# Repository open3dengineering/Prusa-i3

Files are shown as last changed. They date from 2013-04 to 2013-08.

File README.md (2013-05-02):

O3DE-Prusa I3
=============

This is a improved version of the Prusa i3 3D Printer. 

*see [http://reprap.org/wiki/Prusa_i3](http://reprap.org/wiki/Prusa_i3).*

Improvements:
-------------
* Aluminium Frame has now a Y-Plate with 3 points to attach the Heatbed ( compatible with MK2a + MK2b  Heatbed )
* Aluminium Frame had some little bugs + the milling time has decreased to 50%. 
* x-motor-end has been moved 5mm outwards to don't bump into the RAMPS electronics board.
* teeth profile on the x-carriage has been seperated to print better ( teeth part is printed with a 0.3mm nozzle layer height 0.2mm )
* y-beltholder has been improved to print faster
* addons for now a clamp-on spoolholder 
* extruder is addapted from EiNSTeiN variant, with some improvements for printing and usage, added fanholder ( there is still some work to do )

Design tools:
-------------

The Extruder is still in openscad design , the rest ( exept the Aluminium Frame ) was imported into Blender.
The Aluminium Frame has been redesigned in QCAD..

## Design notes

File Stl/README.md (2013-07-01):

O3DE-Prusa I3 stl files
=============

This are all the printed parts, exept the extruder that resigns in ../Extruder/stl.
There are some minor tweaks, please refere to the manual for assembly instructions.

plate-1-04mm.stl 
	* print with 0.4mm layer height 

plate-2-02mm.stl
	* print with 0.2mm layer height

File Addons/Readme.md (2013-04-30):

Addons for the Prus i3 
======================

Spool Holder
------------

The spool holder is clamped ontop into the Aluminium Frame facing to the backside. 
We left enough place so all 1KG spools will fit.

Files:

* i3_spool_holder.stl
* ../Blender/i3_spool_holder.blend

Power Supply Cover
------------------

*Have a look at [http://www.thingiverse.com/thing:40377](http://www.thingiverse.com/thing:40377).*

There are two files 

* Vision_12_Volt_Power_Supply_Cover_-_Final_-_No_Switch_Hole.stl ( without on/off switch)
* Vision_12_Volt_Power_Supply_Cover_-_Final.stl ( with on/off switch)

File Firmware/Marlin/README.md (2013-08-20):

Marlin Firmware for the O3DE-Prusa I3
=============

This is a preconfigured Marlin Firmware for the O3DE-Prusa I3. 

*original [https://github.com/ErikZalm/Marlin/](https://github.com/ErikZalm/Marlin/).*

Installation Instructions:
-------------
* Download Arduino 1.0.5 from *[http://arduino.cc/en/Main/Software](http://arduino.cc/en/Main/Software).*
* Install /ArduinoAddons/Arduino_1.x.x/u8glib_arduino_v1.12.zip into your Arduino library directory *see [http://arduino.cc/en/Guide/Libraries](http://arduino.cc/en/Guide/Libraries)*
* on Windows install arduino Drivers located in the arduino drivers directory ( right click arduino.inf and select install )
* To use the Taurino Classic and Taurino Power ( both Arduino Mega clones ) on Windows 8/7/Vista/XP 32 and 64 bit install the USB driver from [ftp://ftp.open3dengineering.org/pub/Taurino_USB_Driver_Windows/RRD_RUMBA_TAURINO_DriverSetup.exe](ftp://ftp.open3dengineering.org/pub/Taurino_USB_Driver_Windows/RRD_RUMBA_TAURINO_DriverSetup.exe)
* Open /Marlin/Marlin.ino with the Arduino IDE 
* set your Boardtype to "Arduino Mega 2560" and select the coresponding serial interface
* upload the Firmware ( File->Upload )

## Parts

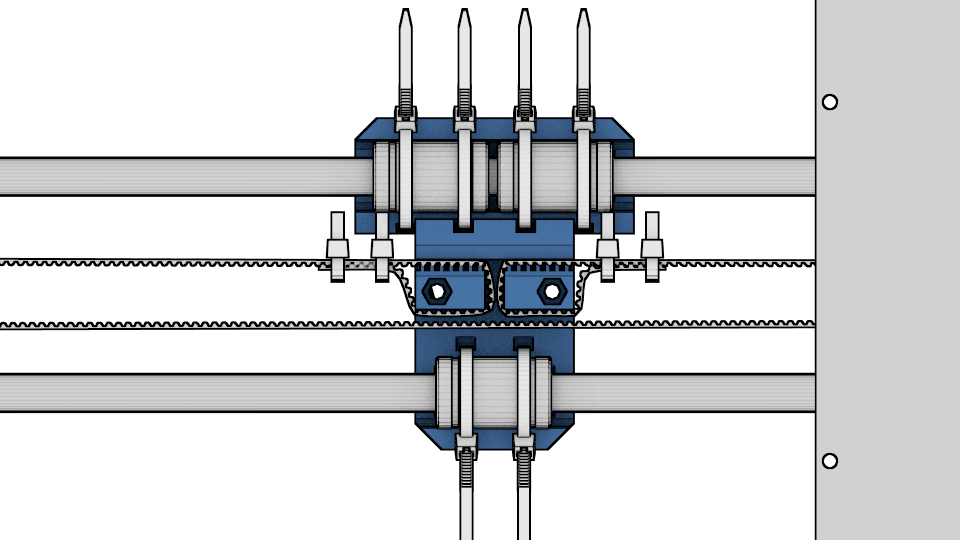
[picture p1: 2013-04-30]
Manual/media/assembed_parts/x8.png

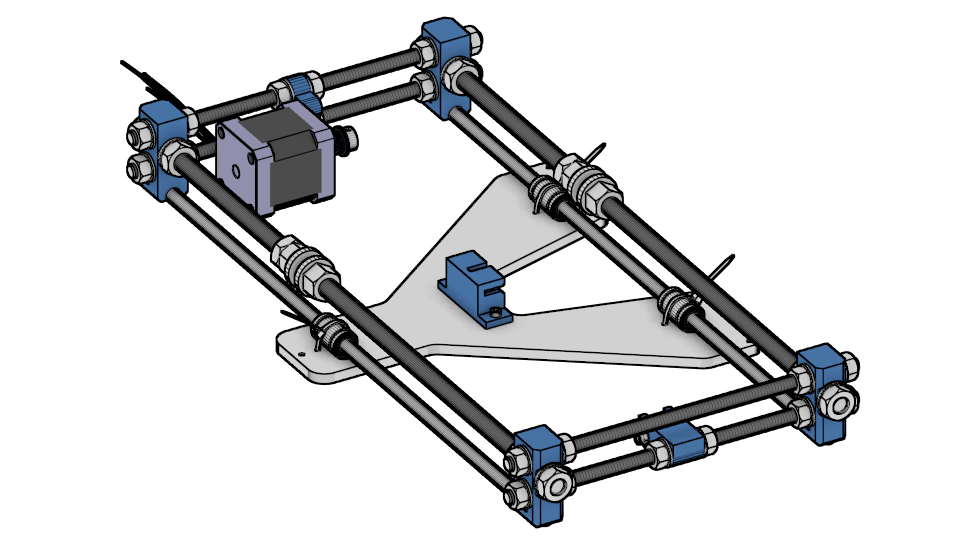
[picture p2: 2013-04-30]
Manual/media/assembed_parts/Y12.png

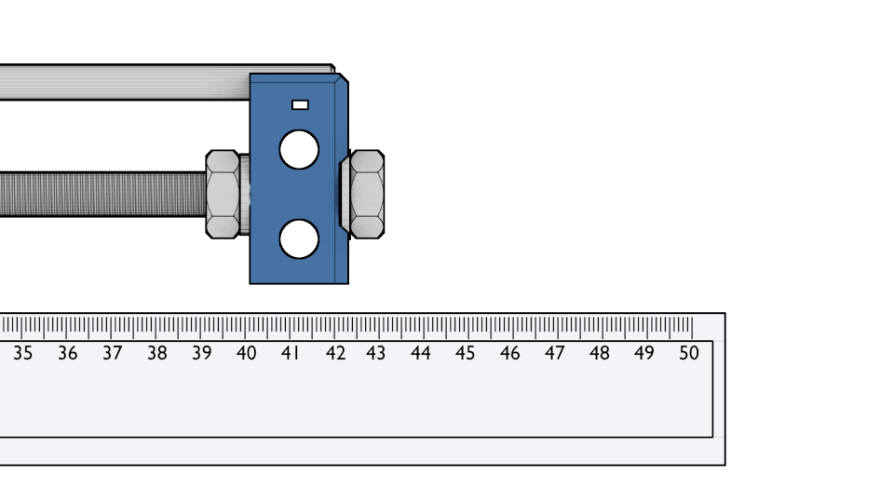
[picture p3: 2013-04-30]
Manual/media/assembed_parts/YA3.png

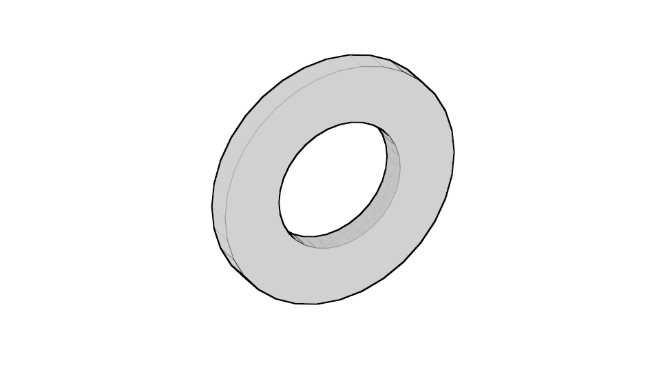
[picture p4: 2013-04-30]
Manual/media/single_parts/DIN 125 M10.png

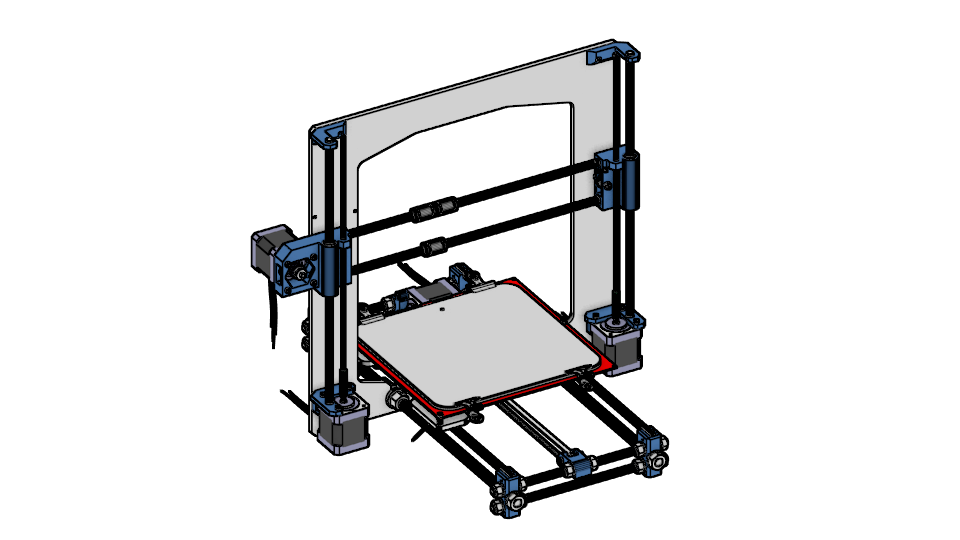
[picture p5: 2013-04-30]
Manual/media/assembed_parts/x5.png

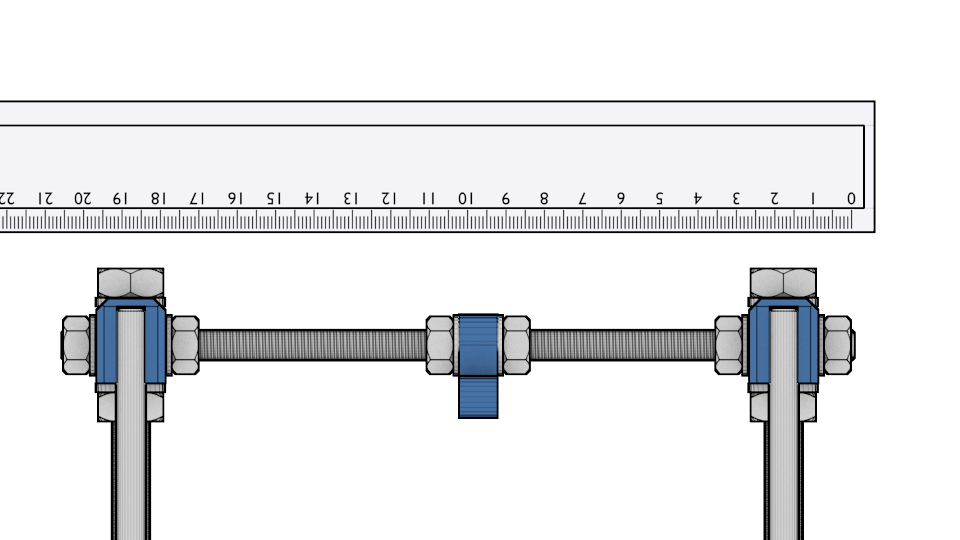
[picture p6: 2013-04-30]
Manual/media/assembed_parts/YA6.png

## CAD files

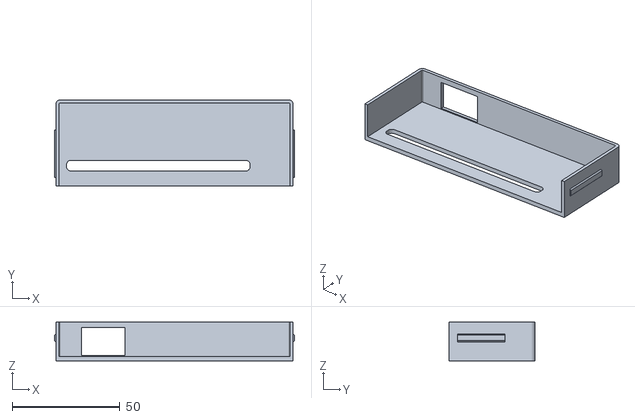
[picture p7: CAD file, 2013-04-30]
Addons/Vision_12_Volt_Power_Supply_Cover_-_Final.stl
111.2 x 40.0 x 18.0

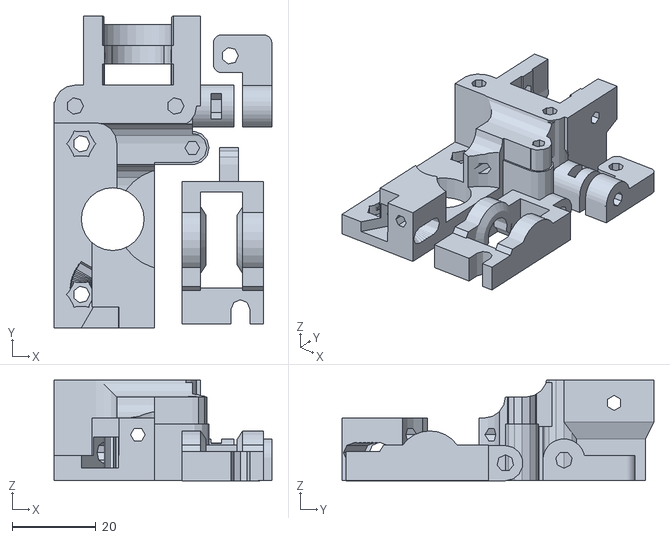
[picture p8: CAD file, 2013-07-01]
Extruder/stl/compact-extruder_o3d_ceramic (repaired).stl
52.0 x 74.5 x 24.0

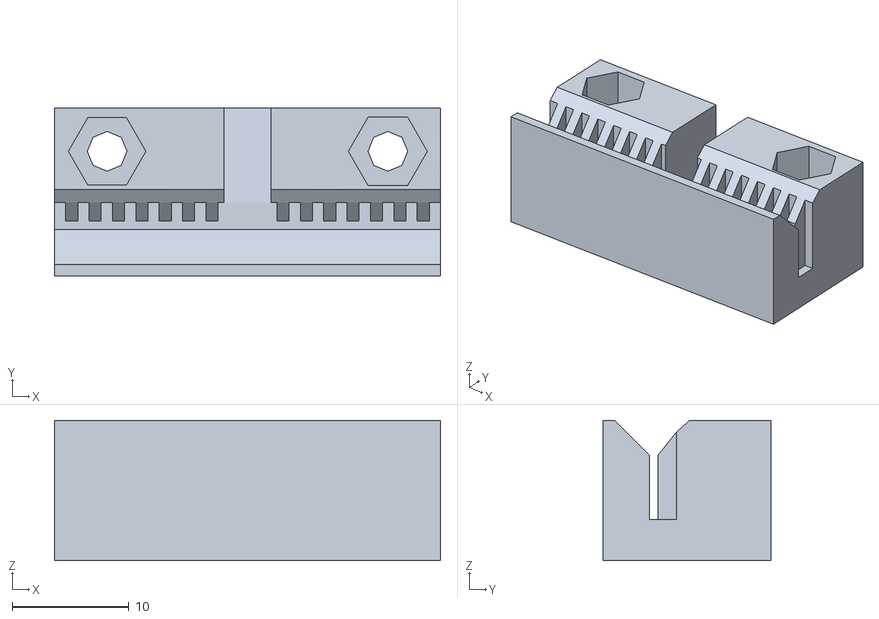
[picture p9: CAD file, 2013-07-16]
Stl/x-carriage-teeth-gt2.stl
33.0 x 14.4 x 12.0

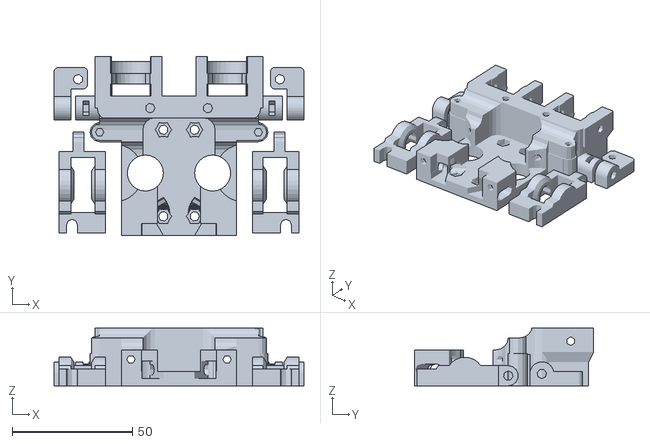
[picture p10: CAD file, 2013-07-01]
Extruder/stl/compact-dual-extruder_o3d_ceramic (repaired).stl
104.0 x 74.5 x 24.0

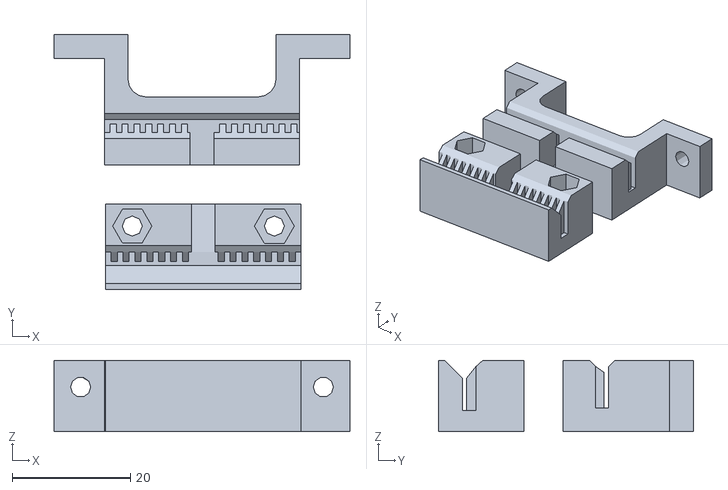
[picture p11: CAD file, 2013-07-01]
Stl/plate-2-02mm.stl
50.0 x 43.0 x 12.0

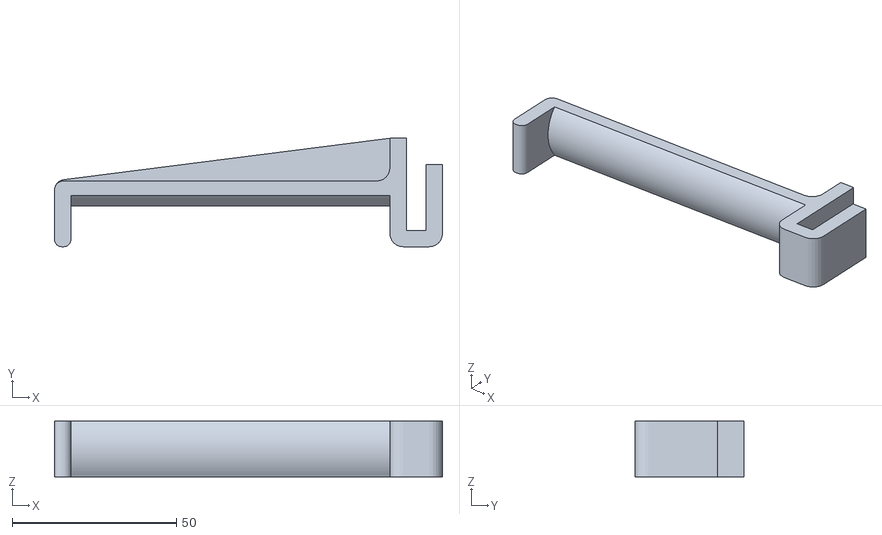
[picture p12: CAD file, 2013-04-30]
Addons/i3_spool_holder.stl
118.0 x 33.0 x 17.0

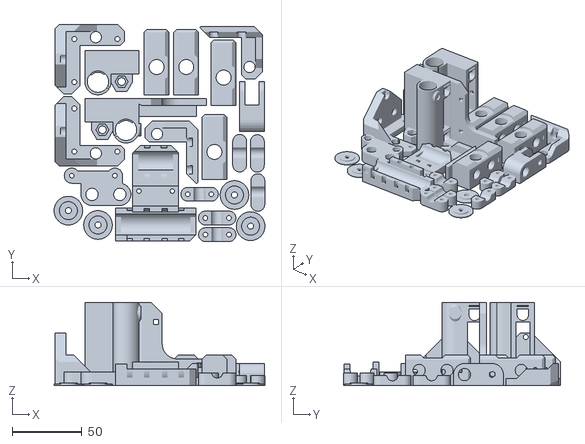
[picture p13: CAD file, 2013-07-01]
Stl/plate-1-04mm.stl
151.8 x 156.2 x 60.0

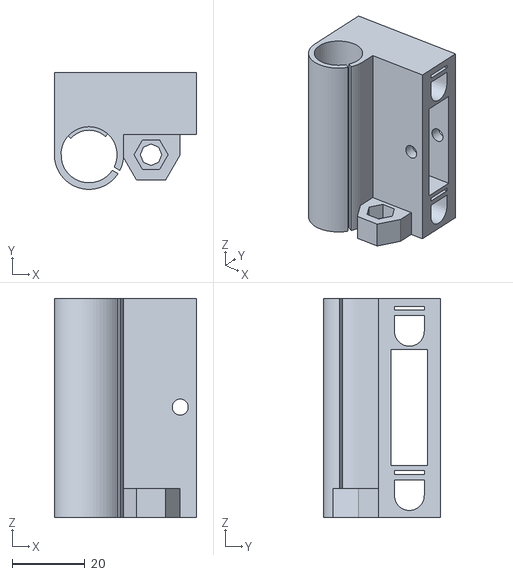
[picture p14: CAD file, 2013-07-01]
Stl/x-idler.stl
39.0 x 32.0 x 60.0

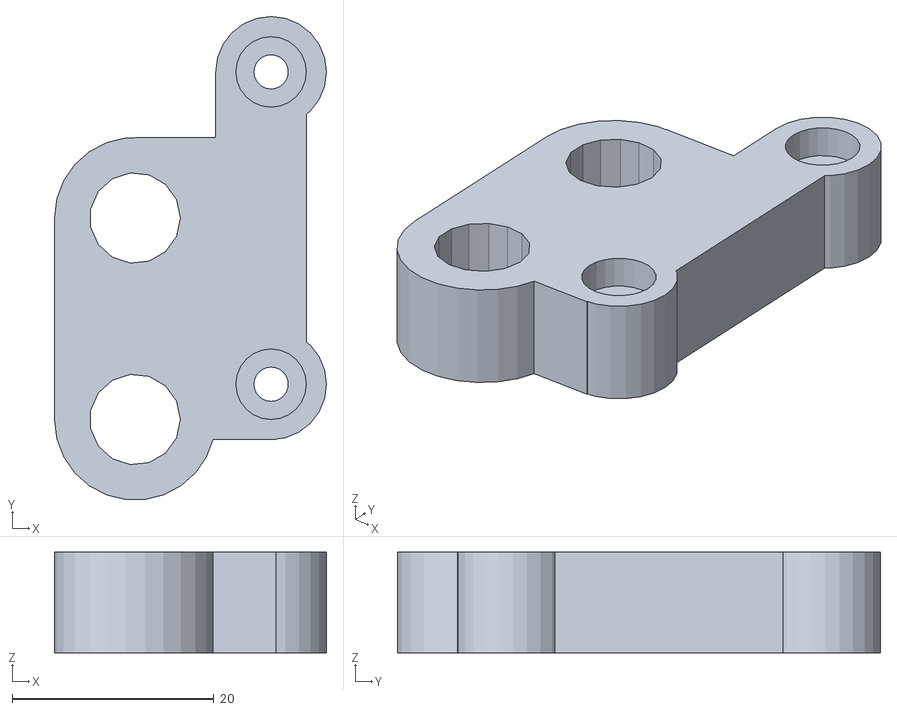
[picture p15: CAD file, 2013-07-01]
Stl/y-motor.stl
27.0 x 47.9 x 10.0

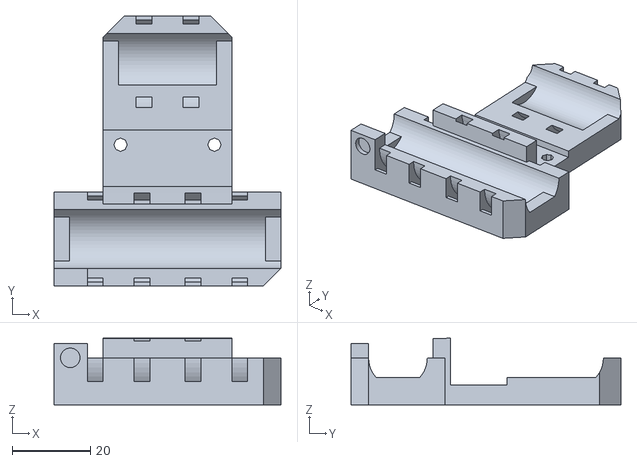
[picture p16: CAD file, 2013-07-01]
Stl/x-carriage-holder.stl
58.0 x 69.0 x 17.0

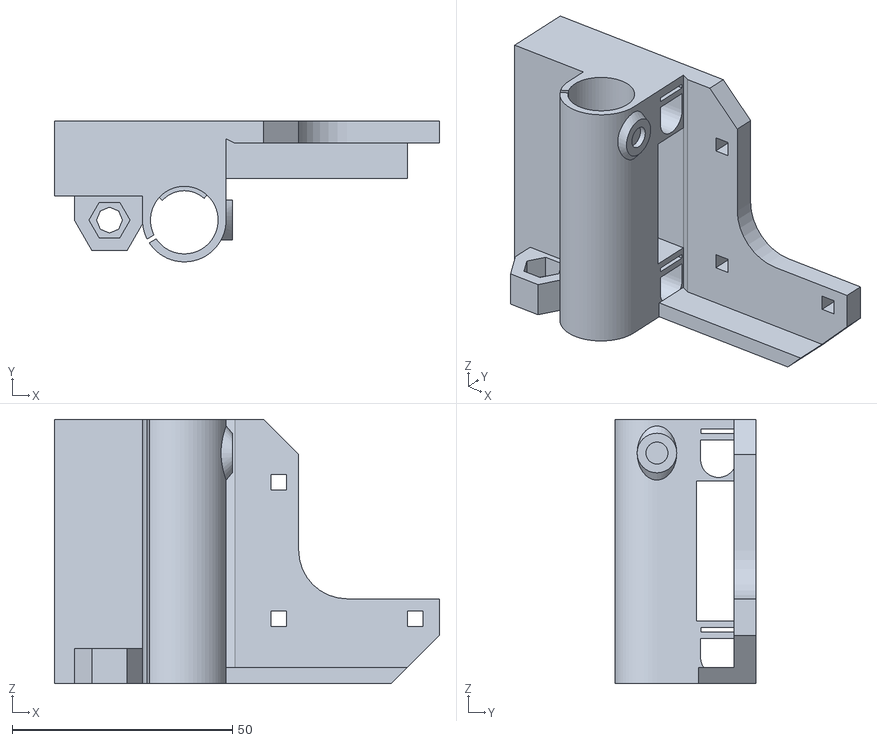
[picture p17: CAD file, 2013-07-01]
Stl/x-motor-end.stl
87.5 x 32.0 x 60.0

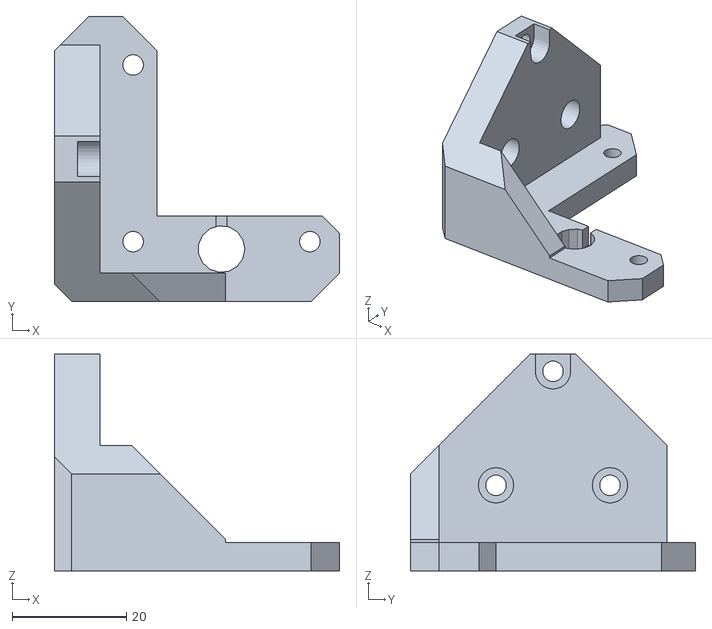
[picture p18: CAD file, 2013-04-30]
Stl/z-bottom-right.stl
50.0 x 50.0 x 38.0

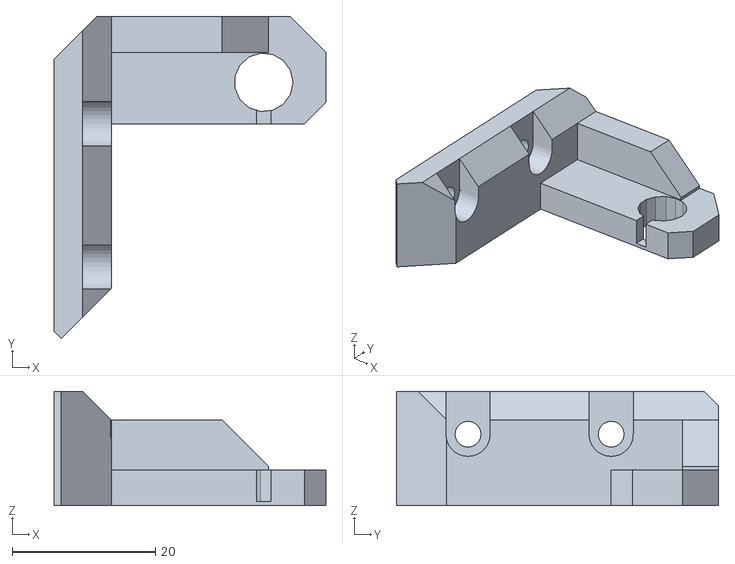
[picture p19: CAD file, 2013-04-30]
Stl/z-top-left.stl
38.0 x 45.0 x 16.0

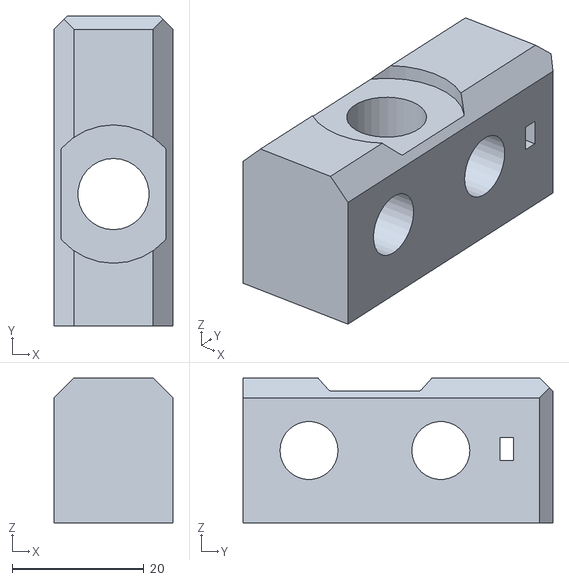
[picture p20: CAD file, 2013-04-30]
Stl/y-corners.stl
18.0 x 47.0 x 22.0

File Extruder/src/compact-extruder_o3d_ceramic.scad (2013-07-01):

// PRUSA iteration3
// Compact extruder
// GNU GPL v3
// Josef Průša <iam@josefprusa.cz> and contributors
// http://www.reprap.org/wiki/Prusa_Mendel
// http://prusamendel.org

dual_extruder = false;

with_vertical_carriage_holes = true;
with_mountplate_holes = false;

// supported hotends: jhead
// comment the line to disable
with_hotend_mount = "jhead";

// supported motors: PG35L, 42BYG48HJ50
//with_motor = "PG35L";
with_motor = "42BYG48HJ50";

// fillment diametert
fillment = 3.5; // 1.75 mm
//fillment = 3.5; // 3 mm

if(dual_extruder && with_mountplate_holes) {
	echo("can't use dual extruder with mountplate!");
}
else {
extruder(vertical_carriage=with_vertical_carriage_holes, mounting_holes=with_mountplate_holes, hotend=with_hotend_mount);

if(with_motor == "PG35L") {
	for(i=dual_extruder ? [0,1] : [0]) mirror([i,0,0])
		translate([19+25+2+6, -9, 8+3]) rotate([0,180,0]) idler();
} else if(with_motor == "42BYG48HJ50") {
	for(i=dual_extruder ? [0,1] : [0]) mirror([i,0,0])
		translate([19+25+2+4, -9, 8+3]) rotate([0,180,0]) idler();
}

// printed rods for the 608zz bearings.
//for(i=[1,2,3])
//	translate([0,i*12-6,0]) cylinder(r=8/2,h=14);
}

///-

module motor() {

	if(with_motor == "PG35L") {
		difference() {
			union() {
			cylinder(h=42.8,r=35/2); // motor body
			// wings..
			difference() {
				hull() {
					intersection() {
						translate([-50/2, -35/2, 0]) cube([50,35/2,5]);
						cylinder(h=5,r=35/2);
					}
					translate([49/2-7.5/2,0,0]) cylinder(h=5,r=7.5/2);
					translate([-49/2+7.5/2,0,0]) cylinder(h=5,r=7.5/2);
				}
				translate([49/2-7.5/2,0,0]) cylinder(h=5,r=3.5/2);
				translate([-49/2+7.5/2,0,0]) cylinder(h=5,r=3.5/2);
			}
			}
			for(i=[0:2]) {
				rotate([0,0,120*i]) translate([0, -35/2+0.5, 23/2]) cube([8, 3, 23], center=true);
			}
		}

		rotate([0,0,15]) translate([0,50/2-7,42.8-13/2-3]) cube([16, 7, 13], center=true);

		translate([0,0,-4.6]) cylinder(h=4.6,r=10/2); // motor shaft
		translate([0,0,-4.6-8]) cylinder(h=8,r=4.8/2); // motor shaft

		// mini hyena: H=10mm, ID=5mm, OD=12.5mm
		#translate([0,0,-5]) rotate([180,0,0]) difference() {
			union() {
				cylinder(h=5.5,r=12.5/2);
				translate([0,0,5.5]) cylinder(h=2,r2=10.5/2, r1=12.5/2);
				translate([0,0,5.5+2]) cylinder(h=2, r2=12.5/2,r1=10.5/2);
				translate([0,0,9.5]) cylinder(h=0.5,r=12.5/2);
			}
			cylinder(h=10,r=5/2);
		}

	}
	else if(with_motor == "42BYG48HJ50") {

		cylinder(h=38,r=42/2);

		difference() {
			translate([-22,-22,0]) cube([44,44,1.2]);
			for(r=[0,90,180,270])
				rotate([0,0,r]) #translate([-36/2,-36/2, 0]) cylinder(h=1.2,r=3.4/2);
		}

		translate([0,(-44/2)+11.5,-14]) cylinder(r=10.88/2,h=14);
	}
	else {
		echo("I don't know this motor type");
	}
}


module nut(d,h,horizontal=true){
    cornerdiameter =  (d / 2) / cos (180 / 6);
    cylinder(h = h, r = cornerdiameter, $fn = 6);
    if(horizontal){
        for(i = [1:6]){
            rotate([0,0,60*i]) translate([-cornerdiameter-0.2,0,0]) rotate([0,0,-45]) cube([2,2,h]);
        }
    }
}

module bolt(length=10, d=3.3) {
	cylinder(r=d/2,h=length);
	translate([0,0,length]) cylinder(r=d*1.5/2,h=3);
}

module jhead_mount() {
   top_d=16;
   top_h=5;
   groove_d=12;
   groove_h=4.5;

   difference() {
	union() {
      translate([5,54-2,0]) cube([top_d+8,top_h+groove_h+7,24]);
	hull() {
        translate([3,54-5,14]) cube([top_d+12,top_h+groove_h+12,10]);
        translate([5,54-2,10]) cube([top_d+8,top_h+groove_h+7,14]);
      }
     }
	 translate([1.5+11+3.5,54,11]) rotate([-90,0,0]) cylinder(r=groove_d/2+0.5, h=top_h+groove_h+1);
	 translate([1.5+11+3.5,54,11]) rotate([-90,0,0]) cylinder(r=top_d/2+0.5, h=top_h);
      hull() {
	    translate([1.5+11+3.5,54,11+(groove_d/2)+1]) rotate([-90,0,0]) cylinder(r=(groove_d+4)/2, h=top_h+groove_h+10);
	    translate([1.5+11+3.5,54,11+15]) rotate([-90,0,0]) cylinder(r=(groove_d+4)/2, h=top_h+groove_h+1);
      }
      hull() {
	    translate([1.5+11+3.5,54,11+(groove_d/2)-1]) rotate([-90,0,0]) cylinder(r=(groove_d+4)/2+0.5, h=top_h);
	    translate([1.5+11+3.5,54,11+15]) rotate([-90,0,0]) cylinder(r=(groove_d+4)/2+0.5, h=top_h);
      }
      hull() {
	    translate([1.5+11+3.5,54+top_h+groove_h,11+(groove_d/2)-1]) rotate([-90,0,0]) cylinder(r=(groove_d+4)/2+0.5, h=top_h+2);
	    translate([1.5+11+3.5,54+top_h+groove_h,11+15]) rotate([-90,0,0]) cylinder(r=(groove_d+4)/2+0.5, h=top_h+5);
      }
	translate([1.5+11+3.5,54+top_h+groove_h,11]) rotate([-90,0,0]) cylinder(r=top_d/2+0.5, h=top_h+5);

	//translate([0,54,12]) cube([33, 2, 20]);
      translate([32,61,18.58]) rotate([0,-90,0]) bolt(length=30, d=3.6);
	
	translate([7.56,54,-12]) cube([16.94, 5, 20]);
   }
   translate([-4,-8,0])fan_mount();
}


module fan_mount() {
	m3_nut_points = 2*((5.3/2)/cos(30));
	m3_nut_depth = 2.5; 


	difference() {
		translate([33,52,0])cube([10,10,10]);
	
		// round top cut
		difference() {
			translate([32,51,0])cube([12,12,11]);
			translate([33,57,5])rotate([0,90,0])cylinder(r=5,h=12,$fn=30);
			translate([33,50,-7])cube([12,14,12]);

		}
		// screw hole
		translate([33,57,5])rotate([0,90,0])cylinder(r=2,h=12);
		translate([37.5,53.85,5])cube([m3_nut_depth,m3_nut_points,10]);
		rotate([0,0,0])translate([37.5,57,5])rotate([0,90,0])rotate([0,0,30])cylinder(r=m3_nut_points/2,h=m3_nut_depth,$fn=6);
}

	translate([12,-7,0])difference() {
		union() {
			translate([33,59,0])cube([7,10,10]);
			//translate([33,69,0])cube([10,10,6]);
			translate([26,69,0])hull () {
				translate([7,0,0])cube ([7,5,6]);
				translate([2,5,0])cylinder(r=2,h=6,$fn=30);
				translate([12,10,0])cylinder(r=2,h=6,$fn=30);
				translate([2,10,0])cylinder(r=2,h=6,$fn=30);
			}

		}	

		// round top cut
		difference() {
			translate([26,58,-1])cube([15,14,12]);
			translate([33,64,5])rotate([0,90,0])cylinder(r=5,h=12,$fn=30);
			translate([33,55,-7])cube([12,14,12]);
			translate([33,65,-6])cube([12,14,12]);		

		}
		// screw holes
		translate([30,64,5])rotate([0,90,0])cylinder(r=2,h=12);
		translate([30,76,-1])rotate([0,0,0])cylinder(r=2,h=12);

	}
}


module j_head_mount_fitpress() {
	translate([40,17,21.9000009])rotate([0,180,0])difference() {
		translate([10,58.5,13.9])cube([20,10,10]);
		translate([4,4,0])jhead_mount();
		jhead_ceramic();
		translate([9.9,63.3,13.9])cube([2.1,3.4,10]);
		translate([28,63.3,13.9])cube([2.1,3.4,10]);
		translate([9,57.5,21.9])cube([22,12,10]);
	}
}



//jhead_ceramic();
module jhead_ceramic() {
translate([30,65,18.58]) rotate([0,-90,0]) bolt(length=30, d=3.3);
translate([20,59.75,11])rotate([-90,0,0])difference() {
	color("red")cylinder(r=14.45/2, h=40);
	//color("red")cylinder(r=11.9/2, h=40);
	translate([0,0,3.25])difference() {
		cylinder(r=12, h= 4.6);
		cylinder(r=11.9/2,h=10);	
	}
	translate([0,0,-1])cylinder(r=3/2,h=50);
}
}


module extruder_42BYG48HJ50_body() {
 // Main body
 translate([-2+2,0,0]) cube([22+2,58-4,24]);
 translate([11-2+2+2,22+1+4-1,0]) {
  translate([11,13.5,12+1]) {
	cube([5+4,14,12-1.5]);
     translate([5+4,3.5,0]) cylinder(r=3.5, h=12-1.5);
  }
  translate([11,13,0]) {
	cube([5+4,8,12+1.5]);
     translate([5+4,4,0]) cylinder(r=4, h=12+1.5);
  }
 }
}




module extruder_42BYG48HJ50_holes() {
 translate([11+2,25-3+4,0]) {
  // Main shaft opening
  translate([1,0,-1]) cylinder(r=7.5, h=26);
  // Lower motor mount hole
  translate([-6.5,18,-1]) cylinder(r=2, h=22);
  // Upper motor mount hole
  translate([-6.5,-18,-1]) cylinder(r=2, h=22);
  // Lower motor mount hole screw head
  translate([-6.5,18,3]) nut(5.8,10);
  // Upper motor mount hole screw head
  translate([-6.5,-18,3]) nut(5.8,10);
  // Idler bearing cutout
  translate([11+3,0,-4.5+10]) cylinder(r=12, h=24);

  // Idler connector, remove some plastic on the upper part.
  translate([11-2+2,13.5+1-1,0]) {
	cube([5+4,7,12+1]);
     #translate([5+4,3.5,0]) cylinder(r=3.5, h=12+1);
  }
  translate([11+5+4-2+2,17+1-1,12+1.5]) bolt(25, 3.5);
 }

 translate([11+2+4,25+4,0]) {
   hull() {
     translate([-15,15,25]) rotate([0,90,0]) cylinder(r=10/2,h=35);
     translate([-20,-30,25]) rotate([0,90,0]) cylinder(r=10/2,h=35);
   }
 }
 translate([11+2,25+4-10,-5]) {
   hull() {
     translate([-15,15,25]) rotate([0,90,0]) cylinder(r=10/2,h=35);
     translate([-20,-30,25]) rotate([0,90,0]) cylinder(r=10/2,h=35);
   }
 }

 // remove material
 hull() {
   translate([4,0,6]) cylinder(r=10/2, h=20);
   translate([4,31,6]) cylinder(r=10/2, h=20);
 }
 //translate([4,23,6]) cylinder(r=18/2, h=20);
 hull() for(x=[-1,10]) {
   translate([x,28,6]) cylinder(r=10/2, h=20);
   translate([x,44,6]) cylinder(r=10/2, h=20);
 }
 translate([5.5,-5,6]) cube([10,10,20]);

 // Filament path
 translate([1.5+11+3.5+2+2,65+4,11]) rotate([90,0,0]) cylinder(r=fillment/2, h=70);
 // Hole for drive gear check
 translate([1.5+11+3.5-30+2,25-3+4,11]) rotate([90,0,90]) cylinder(r=4, h=70, $fn=20);

  translate([12+2,5+4,3]) tiltscrew();
}

module extruder_PG35L_body() {
 // Main body
 translate([-2+2,0,0]) cube([24+6,58-9,24]);

 *%translate([8,40,7]) rotate([0,-90,0]) bearing();
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

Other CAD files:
Frame/frame i3 bdv straight.dwg
Addons/Vision_12_Volt_Power_Supply_Cover_-_Final_-_No_Switch_Hole.stl
Stl/z-bottom-left.stl
Stl/endstop-holder-top.stl
Blender/i3_spool_holder.blend
Extruder/Einstein_CleanUp.blend
Stl/belt-guides.stl
Stl/endstop-holder-bottom.stl
Stl/y-beltholder-gt2.stl
Stl/y-idler.stl
Stl/z-top-right.stl

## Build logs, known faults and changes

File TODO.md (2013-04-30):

Design Todo

X Motor
- Check distance Rods
- Printed laying flat
- Place for magnet
- Integrated with endstop

X Idlder
- Check distance Rods
- Printed laying flat

X Carriage
- Magnet holder
- Clean up zip tie holder
- No colliding timing belt

Y Motor
- Mirror

Y Idler
- Make it nicer

Y General
- Cable places
- Y aluminium Brackets
- Place to fix onto the frame for transport
- Powersupply under the bed
- Balance the position

Z Top
- Close of the ends
- Extra support for m5 Rod?
- Knobs for M5 Rods
- Integrated Cable management?
- Experiment for M5 rod coupling

Z Endstop
- 

Extruder
- Nozzle attached from front
- Place for M4 lock nut
- Clamping tool

Frame
- Pull entlastung for cables
- Possibly to have Y cut plates
- Y should go in a bit deeper
- Place to fix Y onto the frame for transport
- Turn RAMPS 
- Better cable guidance

Extra
- Casing for power supply
- Casing for Ramps
- Casing for Display
- Spool holder
- Grip

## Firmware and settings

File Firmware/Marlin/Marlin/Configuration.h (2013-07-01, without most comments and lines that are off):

#define CONFIGURATION_H
#define STRING_VERSION_CONFIG_H __DATE__ " " __TIME__ // build date and time
#define STRING_CONFIG_H_AUTHOR "(none, default config)" //Who made the changes.
#define SERIAL_PORT 0
#define BAUDRATE 250000
#define MOTHERBOARD 33
#define EXTRUDERS 1
#define POWER_SUPPLY 1
#define TEMP_SENSOR_0 57
#define TEMP_SENSOR_1 0
#define TEMP_SENSOR_2 0
#define TEMP_SENSOR_BED 58
#define TEMP_RESIDENCY_TIME 10  // (seconds)
#define TEMP_HYSTERESIS 3       // (degC) range of +/- temperatures considered "close" to the target one
#define TEMP_WINDOW     1       // (degC) Window around target to start the recidency timer x degC early.
#define HEATER_0_MINTEMP 5
#define HEATER_1_MINTEMP 5
#define HEATER_2_MINTEMP 5
#define BED_MINTEMP 5
#define HEATER_0_MAXTEMP 260
#define HEATER_1_MAXTEMP 260
#define HEATER_2_MAXTEMP 260
#define BED_MAXTEMP 150
#define BANG_MAX 256 // limits current to nozzle while in bang-bang mode; 256=full current
#define PID_MAX 256 // limits current to nozzle while PID is active (see PID_FUNCTIONAL_RANGE below); 256=full current
#define MAX_BED_POWER 256 // limits duty cycle to bed; 256=full current
#define PREVENT_DANGEROUS_EXTRUDE
#define PREVENT_LENGTHY_EXTRUDE
#define EXTRUDE_MINTEMP 170
#define EXTRUDE_MAXLENGTH (X_MAX_LENGTH+Y_MAX_LENGTH) //prevent extrusion of very large distances.
#define ENDSTOPPULLUPS // Comment this out (using // at the start of the line) to disable the endstop pullup resistors
  #define ENDSTOPPULLUP_XMAX
  #define ENDSTOPPULLUP_YMAX
  #define ENDSTOPPULLUP_ZMAX
  #define ENDSTOPPULLUP_XMIN
  #define ENDSTOPPULLUP_YMIN
  #define ENDSTOPPULLUP_ZMIN
const bool X_ENDSTOPS_INVERTING = true; // set to true to invert the logic of the endstops.
const bool Y_ENDSTOPS_INVERTING = true; // set to true to invert the logic of the endstops.
const bool Z_ENDSTOPS_INVERTING = true; // set to true to invert the logic of the endstops.
#define X_ENABLE_ON 0
#define Y_ENABLE_ON 0
#define Z_ENABLE_ON 0
#define E_ENABLE_ON 0 // For all extruders
#define DISABLE_X false
#define DISABLE_Y false
#define DISABLE_Z false
#define DISABLE_E false // For all extruders
#define INVERT_X_DIR true    // for Mendel set to false, for Orca set to true
#define INVERT_Y_DIR false    // for Mendel set to true, for Orca set to false
#define INVERT_Z_DIR true     // for Mendel set to false, for Orca set to true
#define INVERT_E0_DIR false   // for direct drive extruder v9 set to true, for geared extruder set to false
#define INVERT_E1_DIR false    // for direct drive extruder v9 set to true, for geared extruder set to false
#define INVERT_E2_DIR false   // for direct drive extruder v9 set to true, for geared extruder set to false
#define X_HOME_DIR -1
#define Y_HOME_DIR -1
#define Z_HOME_DIR -1
#define min_software_endstops true //If true, axis won't move to coordinates less than HOME_POS.
#define max_software_endstops true  //If true, axis won't move to coordinates greater than the defined lengths below.
#define X_MAX_POS 205
#define X_MIN_POS 0
#define Y_MAX_POS 205
#define Y_MIN_POS 0
#define Z_MAX_POS 200
#define Z_MIN_POS 0
#define X_MAX_LENGTH (X_MAX_POS - X_MIN_POS)
#define Y_MAX_LENGTH (Y_MAX_POS - Y_MIN_POS)
#define Z_MAX_LENGTH (Z_MAX_POS - Z_MIN_POS)
#define MANUAL_X_HOME_POS 0
#define MANUAL_Y_HOME_POS 0
#define MANUAL_Z_HOME_POS 0
#define NUM_AXIS 4 // The axis order in all axis related arrays is X, Y, Z, E
#define HOMING_FEEDRATE {50*60, 50*60, 2.5*60, 0}  // set the homing speeds (mm/min)
#define DEFAULT_AXIS_STEPS_PER_UNIT   {80, 80, (200.0*8/0.8)*1, 1178}  // default steps per unit for ultimaker
#define DEFAULT_MAX_FEEDRATE          {500, 500, 2, 45}    // (mm/sec)
#define DEFAULT_MAX_ACCELERATION      {9000,9000,100,300}    // X, Y, Z, E maximum start speed for accelerated moves. E default values are good for skeinforge 40+, for older versions raise them a lot.
#define DEFAULT_ACCELERATION          3000    // X, Y, Z and E max acceleration in mm/s^2 for printing moves
#define DEFAULT_RETRACT_ACCELERATION  300   // X, Y, Z and E max acceleration in mm/s^2 for r retracts
#define DEFAULT_XYJERK                20.0    // (mm/sec)
#define DEFAULT_ZJERK                 0.4     // (mm/sec)
#define DEFAULT_EJERK                 2.0    // (mm/sec)
#define PLA_PREHEAT_HOTEND_TEMP 180
#define PLA_PREHEAT_HPB_TEMP 70
#define PLA_PREHEAT_FAN_SPEED 255   // Insert Value between 0 and 255
#define ABS_PREHEAT_HOTEND_TEMP 240
#define ABS_PREHEAT_HPB_TEMP 100
#define ABS_PREHEAT_FAN_SPEED 255   // Insert Value between 0 and 255
#define REPRAP_DISCOUNT_FULL_GRAPHIC_SMART_CONTROLLER
 #define DOGLCD
 #define U8GLIB_ST7920
 #define REPRAP_DISCOUNT_SMART_CONTROLLER
 #define ULTIPANEL
 #define NEWPANEL
  #define SDSUPPORT
  #define ULTRA_LCD
    #define LCD_WIDTH 20
    #define LCD_HEIGHT 5
#include "Configuration_adv.h"
#include "thermistortables.h"

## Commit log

2013-04-30 added Power_Supply_Cover thanks to Martin Daske
    [Vision_12_Volt_Power_Supply_Cover_-_Final.stl, Vision_12_Volt_Power_Supply_Cover_-_Final_-_No_Switch_Hole.stl]
2013-05-04 added Marlin Firmware with default settings
    [Configuration.h, Configuration_adv.h, Menu Plans.xlsx]
2013-06-01 changed defalt thermistor table for Hetbed in thermistortables.h
2013-06-02 Marlin update with GLCD support and undef PIDTEM bugfix
    [Configuration.h, Configuration_adv.h, Menu Plans.xlsx]
2013-06-02 created new subdirectory Marlin for compatibility
    [Configuration.h, Configuration_adv.h, Menu Plans.xlsx]
2013-06-02 added Readme.md for Marlin Firmware
2013-06-02 changed Readme.md for Marlin Firmware
2013-06-10 changed Homing Feedrate for Z in Configuration.h
    [Configuration.h]
2013-07-01 changes to stl's, blender file and firmware
    [Configuration.h, compact-dual-extruder_o3d_ceramic (repaired).stl, compact-extruder_o3d_ceramic (repaired).stl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]
2013-07-03 added Hall-O-Endstops to the blender Model
2013-07-16 fixed x-carriage-teeth-gt2, all normals where flipped
    [x-carriage-teeth-gt2.stl]
2013-07-17 added Taurion USB driver for Windows
2013-10-02 New Einstein extruder design, cleaned up stl.
    [Einstein_CleanUp.blend]
